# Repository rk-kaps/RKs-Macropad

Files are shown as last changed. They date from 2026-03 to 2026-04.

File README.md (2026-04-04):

<h1 align="center">RKs Macropad</h1>

<p align="center">
  Welcome to RKs Macropad, my custom 3D printed Macropad that runs KMK firmware.
</p>

<p align="center">
  Main
</p>

<p align="center">
  Exploded
</p>

<hr>
<h2>PCB & Schematic</h2>
<p align="center">
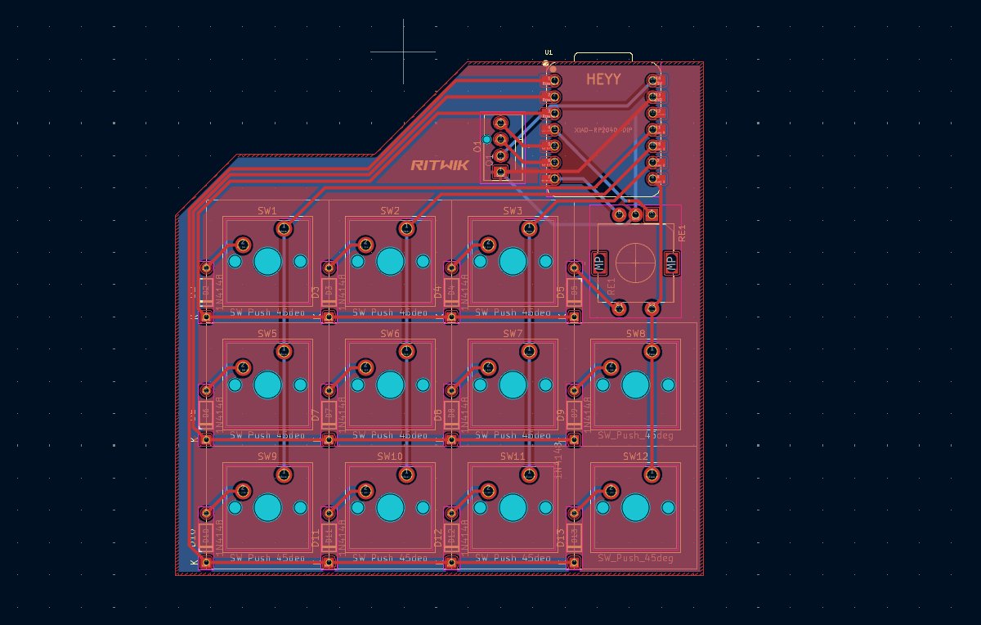
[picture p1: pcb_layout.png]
PCB Layout
  
  <br><em>PCB Layout (KiCad)</em>
</p>
<p align="center">
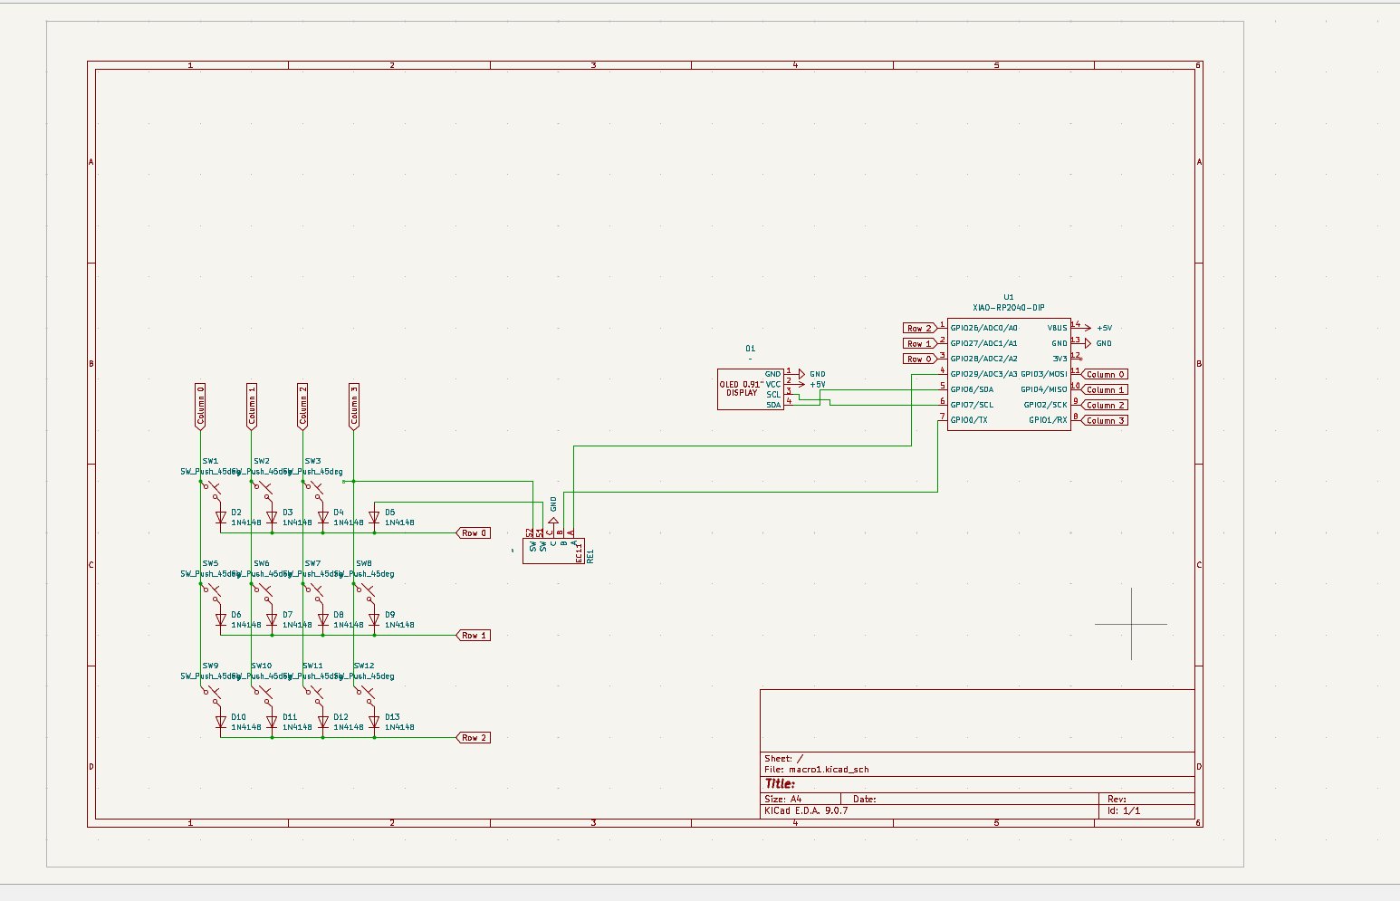
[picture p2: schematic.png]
Schematic
  
  <br><em>Schematic</em>
</p>
<p align="center">
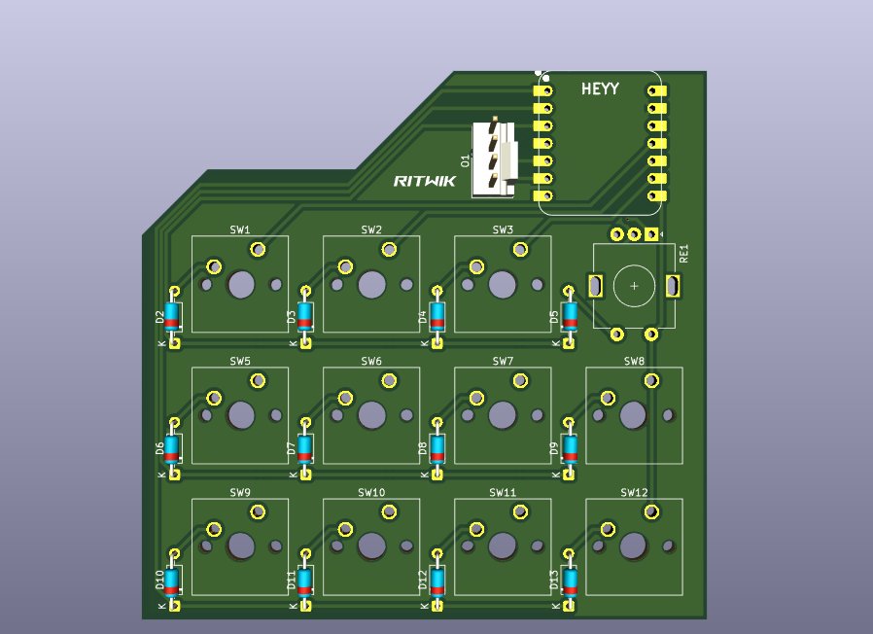
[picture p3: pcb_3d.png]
PCB 3D View
  
  <br><em>PCB 3D Render</em>
</p>

<h2>Motivation</h2>
<ul>>
MacroPad began as a simple rotary encoder-based volume controller. It evolved into a fully-featured macropad focused on:

Speeding up workflows
Reducing repetitive actions
Providing intuitive visual feedback
Maximizing functionality within hardware constraints
</ul>
</h2>
<h2> Project Highlights  </h2>
<ul>
- Efficient use of limited GPIO resources  
- Custom analog decoding for rotary encoder  
- Integration of hardware + firmware + UI design  
- Fully functional productivity tool
</ul>
<hr>

<h2>Bill of Materials:</h2>

<ul>
  <li>1x Rks Macropad PCB</li>
  <li>1x XIAO-PR2040-DIP</li>
  <li>1x EC11 rotary encoder</li>
  <li>11x Cherry MX (or equivalent) keyswitches</li>
  <li>11x Keycaps</li>
  <li>12x 1N4148 Throughhole diodes</li>
  <li>1x 0.91 inch OLED display (SSD1306 I2C 0.91 128x32)</li>
  <li>4x Cap head M3x16 machine screws</li>
  <li>1x 3D printed shell top half</li>
  <li>1x 3D printed shell bottom half</li>
</ul>

<p>
  small amount of spare wire apprx. 50mm worth.
</p>
<hr>
<h2>Instructions for Assembly</h2>
<ol>
  <li>Solder RP2040 directly onto the PCB without a header.</li>
  <li>Solder on diodes aligning with the silkscreen.</li>
  <li>Solder Cherry MX switches to board.</li>
  <li>
    Solder breakout cables to the spare 4 pins near the RP2040 — these will be used to wire to the OLED display.
    Make these breakout cables ~2" to allow for easier soldering.
  </li>
  <li>
    Clamshell the base around the PCB, passing the breakout cables through the small hole in the gap for the display
    in the top half of the case, then use the M3x16 machine screws to clamp the assembly together.
  </li>
  <li>Solder display to the breakout cables.</li>
  <li>Use double-sided tape or a light adhesive to hold the OLED into its holder.</li>
</ol>
<hr>
<h2>Acknowledgements</h2>
<ul>
- KMK Firmware Community  
- Good people of Hack Club
</ul>
<hr>

<h2>Instructions for Assembly:</h2>

<ol>
  <li>Solder RP2040 directly onto the pcb without a header.</li>
  <li>Solder on Diodes aligning with the slikscreen.</li>
  <li>Solder CherryMX switches to board.</li>
  <li>
    Solder breakout cables to the spare 4 pins near the RP2040, these will be used to wire to the OLED display.
    Make these breakout cables ~2" to allow for easier soledering.
  </li>
  <li>
    Clamshell the base around the PCB, passing the breakout cables through the small hole in the gap for the display
    in the top half of the case, then use the M3x16 machine screws to clamp the assembly together.
  </li>

  <li>Solder display to the breakout cables</li>
  <li>Use double-sided tape or a light adhesive to hold the OLED into its holder,.</li>

<h2> Acknowledgements  </h2>
<ul>
- KMK Firmware Community  
- Good people of Hack Club</ul>

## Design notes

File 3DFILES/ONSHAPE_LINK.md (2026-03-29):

# Rks Macropad — Onshape CAD Document

 [Open in Onshape]https://cad.onshape.com/documents/129b0d111c52e735cc28273f

## Exported Files

The full assembly is also available as a STEP file for use in any CAD software

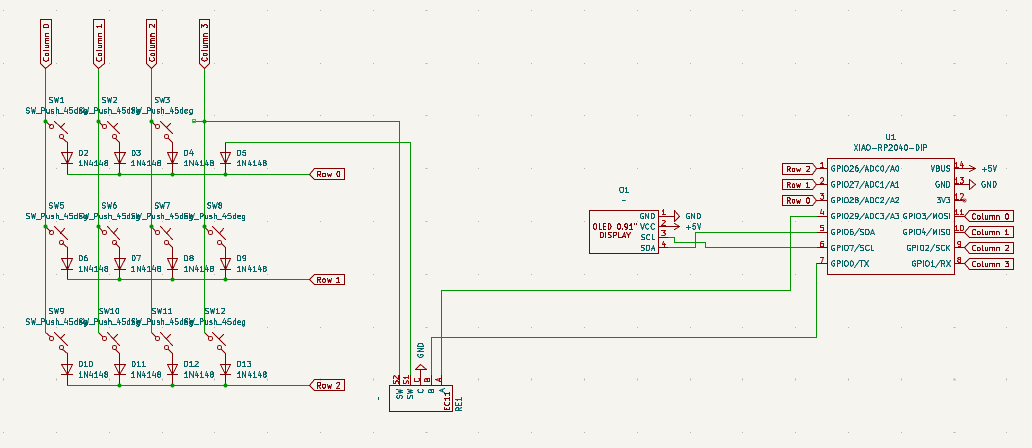
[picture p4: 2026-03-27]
README/Schematic.png

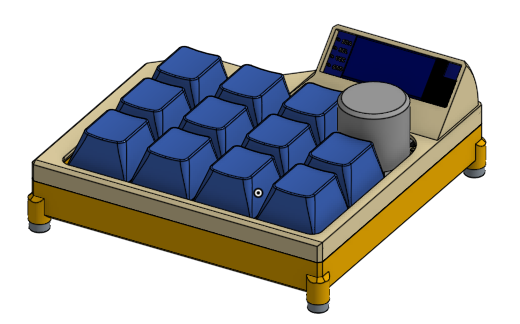
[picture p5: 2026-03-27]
README/Main.png

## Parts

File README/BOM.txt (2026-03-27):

Bill of Materials:
1x CyberDock PCB
1x XIAO-PR2040-DIP
1x EC11 rotary encoder
11x Cherry MX (or equivalent) keyswitches
11x Keycaps
12x 1N4148 Throughhole diodes
1x 0.91 inch OLED display (SSD1306 I2C 0.91 128x32)
4x Cap head M3x16 machine screws
1x 3D printed shell top half
1x 3D printed shell bottom half

small amount of spare wire apprx. 50mm worth.

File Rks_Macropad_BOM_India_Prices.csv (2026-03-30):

Ref | Component | Manufacturer | Qty | Unit Price (₹) | Total (₹) | Store | Link
PCB | Rks Macropad PCB | Custom | 1 | 250 | 250 | JLCPCB | https://jlcpcb.com
MCU | XIAO-RP2040-DIP | Seeed Studio | 1 | 914 | 914 | Robocraze | https://robocraze.com/products/seeed-studio-xiao-rp2040-development-board
ENC | EC11 Rotary Encoder w/ Push Button | Hongyan | 1 | 52 | 52 | Robu.in | https://robu.in/product/hongyan-ec11h-7ce15p1zy15f7-rotary-encoder-with-push-button-switch-vertical-plug-in/
SW | Cherry MX RGB Switch (pack of 10) | Cherry | 2 | 350 | 700 | Meckeys | https://meckeys.com/shop/accessories/keyboard-accessories/key-switches/cherry-mx-rgb-switch/
KP | Keycaps MX compatible (set) | Generic | 1 | 499 | 499 | Meckeys | https://meckeys.com/category/accessories/keyboard-accessories/keycaps/
D | 1N4148 Through-hole Diode | OnSemi | 12 | 1 | 12 | Robu.in | https://robu.in/product/diode-1n4148/
OLED | 0.91" OLED SSD1306 I2C 128x32 | Generic | 1 | 149 | 149 | Robu.in | https://robu.in/product/0-91-inch-128x32-i2c-iic-serial-blue-oled-lcd-display-module/
SCR | Cap Head M3x16 Allen Bolt (12 pcs) | EasyMech | 1 | 89 | 89 | Robu.in | https://robu.in/product/easymech-set-m3-x-16mm-socket-head-cap-allen-bolt-nut-12-pcs/
SHL-T | 3D Printed Shell - Top Half | will get it -printed | 1 | 150 | 150 | 3Ding.in | https://www.3ding.in
SHL-B | 3D Printed Shell - Bottom Half | will get it -printed | 1 | 150 | 150 | 3Ding.in | https://www.3ding.in
 |  |  |  | TOTAL | 2965

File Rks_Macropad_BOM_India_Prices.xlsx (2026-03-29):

Rks Macropad — Bill of Materials (India Prices, Mar 2026)
Ref | Component | Manufacturer | Qty | Unit Price (₹) | Total (₹) | Store | Link
PCB | Rks Macropad PCB | Custom | 1 | 250 |  | JLCPCB | Link (https://jlcpcb.com)
MCU | XIAO-RP2040-DIP | Seeed Studio | 1 | 914 |  | Robocraze | Link (https://robocraze.com/products/seeed-studio-xiao-rp2040-development-board)
ENC | EC11 Rotary Encoder w/ Push Button | Hongyan | 1 | 52 |  | Robu.in | Link (https://robu.in/product/hongyan-ec11h-7ce15p1zy15f7-rotary-encoder-with-push-button-switch-vertical-plug-in/)
SW | Cherry MX RGB Switch (pack of 10) | Cherry | 2 | 350 |  | Meckeys | Link (https://meckeys.com/shop/accessories/keyboard-accessories/key-switches/cherry-mx-rgb-switch/)
KP | Keycaps MX compatible (set) | Generic | 1 | 499 |  | Meckeys | Link (https://meckeys.com/category/accessories/keyboard-accessories/keycaps/)
D | 1N4148 Through-hole Diode | OnSemi | 12 | 1 |  | Robu.in | Link (https://robu.in/product/diode-1n4148/)
OLED | 0.91" OLED SSD1306 I2C 128x32 | Generic | 1 | 149 |  | Robu.in | Link (https://robu.in/product/0-91-inch-128x32-i2c-iic-serial-blue-oled-lcd-display-module/)
SCR | Cap Head M3x16 Allen Bolt (12 pcs) | EasyMech | 1 | 89 |  | Robu.in | Link (https://robu.in/product/easymech-set-m3-x-16mm-socket-head-cap-allen-bolt-nut-12-pcs/)
SHL-T | 3D Printed Shell - Top Half | Self-printed | 1 | 150 |  | 3Ding.in | Link (https://www.3ding.in)
SHL-B | 3D Printed Shell - Bottom Half | Self-printed | 1 | 150 |  | 3Ding.in | Link (https://www.3ding.in)
 |  |  |  | TOTAL:
* Prices are approximate as of March 2026. PCB & 3D print costs are estimates. Cherry MX pack of 10 ordered x2 for 11 switches needed.

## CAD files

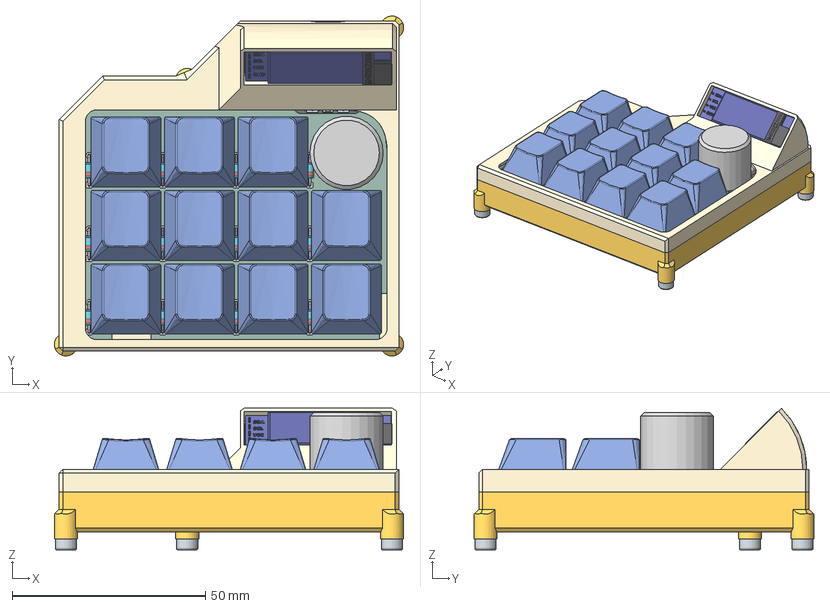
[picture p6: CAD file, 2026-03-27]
3DFILES/macro.step
90.5 x 88.1 x 36.7 mm
Hex socket head cap screw M3x0.50 x 16 x 4
r1_100 x 11
Case Bottom
Case Top
MX? ??LEDLEDLED x 55
MX ? ??��_�?�__ x 11
??___??__�_ x 22
MX ? ???_�___�1 x 11
MX? ?? ?? ?�2__??_�2____�_ x 11
Knob
��ת������ x 6
type-c v2 x 24
main x 16
smd_button v3
smd_button v3(Mirror)
VSS
VDD
DIN
DOUT
D_DO-35_SOD27_P7.62mm_Horizontal x 24

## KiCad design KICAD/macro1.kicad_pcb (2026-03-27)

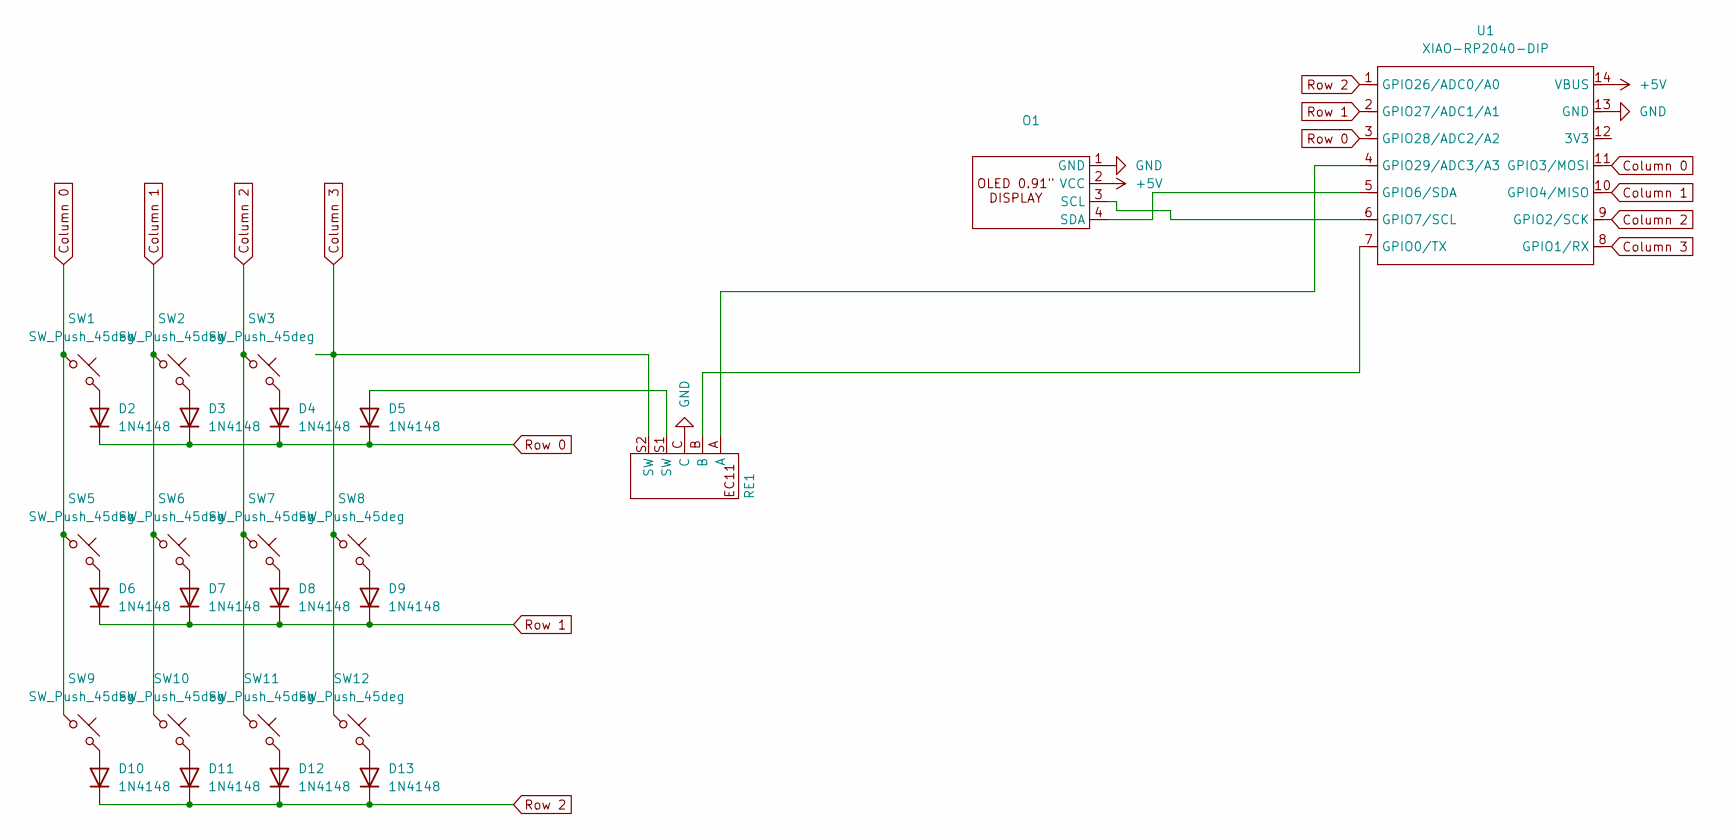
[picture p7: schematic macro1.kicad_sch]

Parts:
D2, D3, D4, D5, D6, D7, D8, D9, D10, D11, D12, D13: 1N4148; D_DO-35_SOD27_P7.62mm_Horizontal
O1: FanPinHeader_1x04_P2.54mm_Vertical
RE1: RotaryEncoder_Alps_EC11E-Switch_Vertical_H20mm
SW1, SW2, SW3, SW5, SW6, SW7, SW8, SW9, SW10, SW11, SW12: SW_Push_45deg; SW_Cherry_MX_1.00u_PCB
U1: XIAO-RP2040-DIP

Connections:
+5V: O1.2 (VCC), U1.14 (VBUS)
Column 0: SW1.1, SW5.1, SW9.1, U1.11 (GPIO3/MOSI)
Column 1: SW2.1, SW6.1, SW10.1, U1.10 (GPIO4/MISO)
Column 2: SW3.1, SW7.1, SW11.1, U1.9 (GPIO2/SCK)
Column 3: RE1.S2 (SW), SW8.1, SW12.1, U1.8 (GPIO1/RX)
GND: O1.1 (GND), RE1.C, U1.13 (GND)
unnamed: D2.2 (A), SW1.2
unnamed: D3.2 (A), SW2.2
unnamed: D4.2 (A), SW3.2
unnamed: D5.2 (A), RE1.S1 (SW)
unnamed: D6.2 (A), SW5.2
unnamed: D7.2 (A), SW6.2
unnamed: D8.2 (A), SW7.2
unnamed: D9.2 (A), SW8.2
unnamed: D10.2 (A), SW9.2
unnamed: D11.2 (A), SW10.2
unnamed: D12.2 (A), SW11.2
unnamed: D13.2 (A), SW12.2
unnamed: O1.3 (SCL), U1.6 (GPIO7/SCL)
unnamed: O1.4 (SDA), U1.5 (GPIO6/SDA)
unnamed: RE1.B, U1.7 (GPIO0/TX)
unnamed: RE1.A, U1.4 (GPIO29/ADC3/A3)
Row 0: D2.1 (K), D3.1 (K), D4.1 (K), D5.1 (K), U1.3 (GPIO28/ADC2/A2)
Row 1: D6.1 (K), D7.1 (K), D8.1 (K), D9.1 (K), U1.2 (GPIO27/ADC1/A1)
Row 2: D10.1 (K), D11.1 (K), D12.1 (K), D13.1 (K), U1.1 (GPIO26/ADC0/A0)

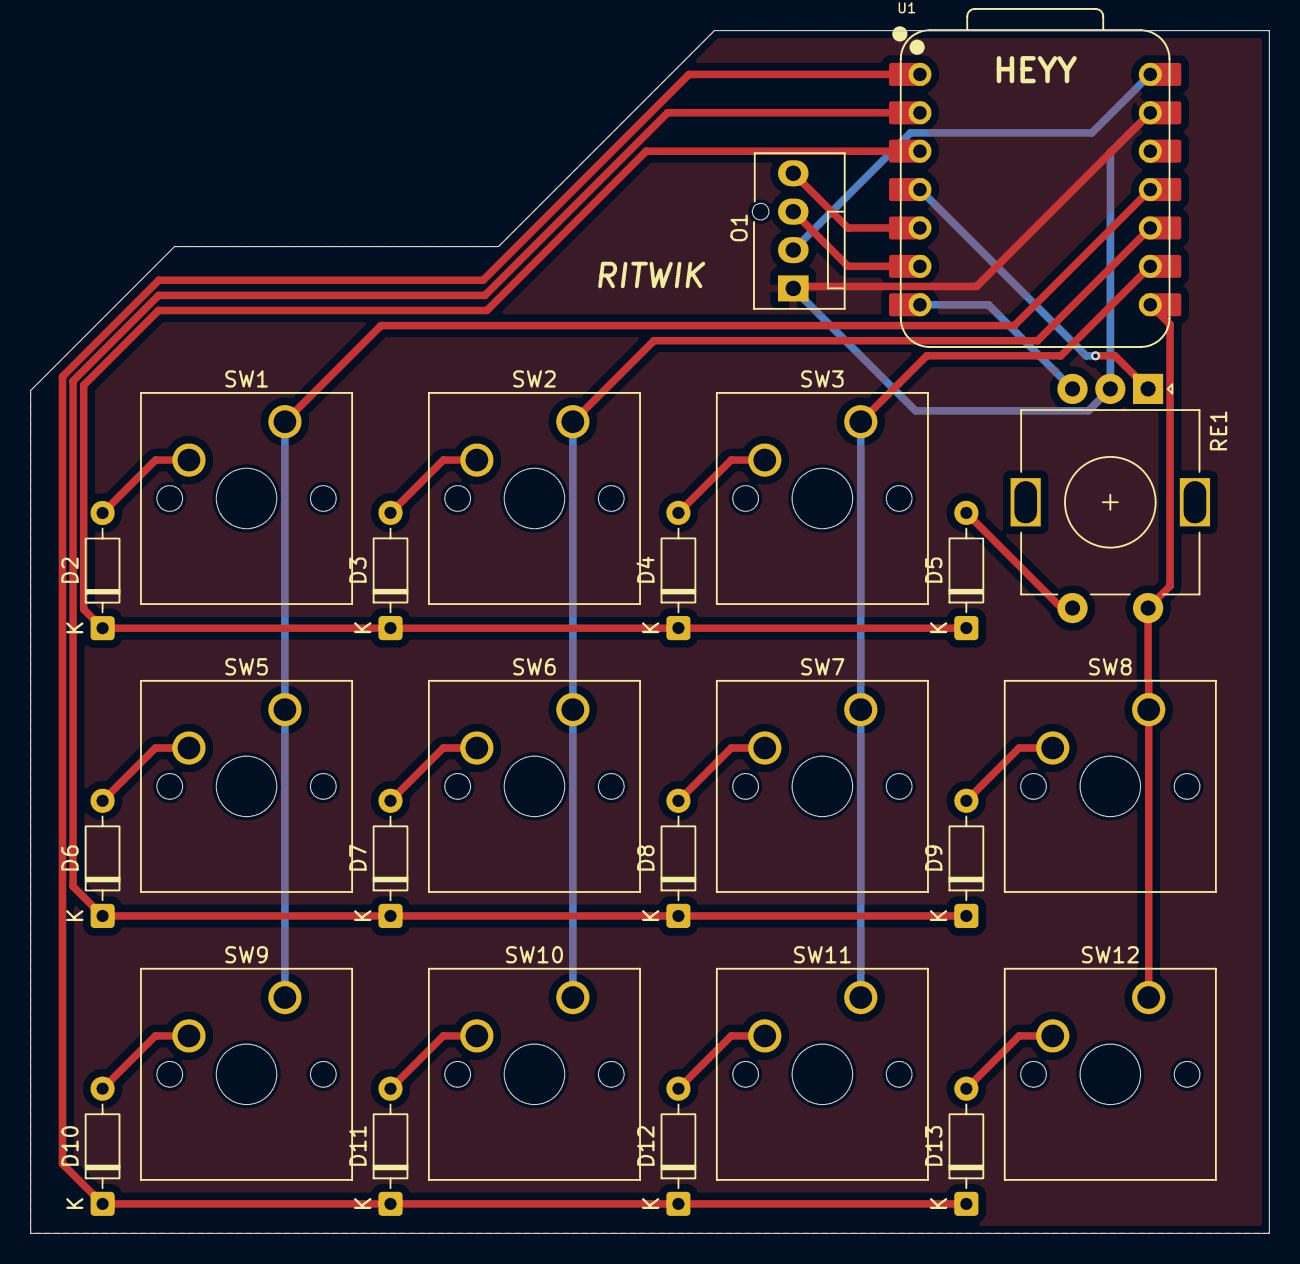
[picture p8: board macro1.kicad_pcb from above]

Board: 2 copper layers, 82.0 x 79.6 mm, 26 parts (0 on the bottom side), 25 nets.

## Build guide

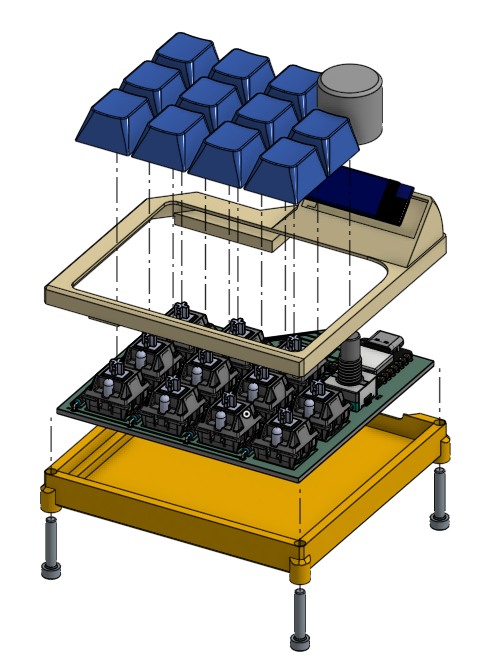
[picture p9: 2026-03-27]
README/deconstructed_view.png

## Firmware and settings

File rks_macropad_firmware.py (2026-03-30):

print("Starting Rks Macropad")
import board
import busio
import digitalio
import time
from kmk.kmk_keyboard import KMKKeyboard
from kmk.keys import KC
from kmk.scanners import DiodeOrientation
from kmk.extensions.media_keys import MediaKeys
from kmk.modules.layers import Layers
import adafruit_ssd1306

# --- OLED Setup ---
# IMPORTANT: Due to the display orientation in this build, the OLED is connected
# via breakout wires (not directly plugged into the PCB).
# Wire connections from Waveshare RP2040-Zero to SSD1306 OLED:
#   VCC  -> 3.3V pin on RP2040-Zero  ⚠️ DO NOT use 5V/VBUS — will damage the display
#   GND  -> GND
#   SDA  -> GP6
#   SCL  -> GP7
i2c = busio.I2C(board.GP7, board.GP6)  # SCL=GP7, SDA=GP6
oled = adafruit_ssd1306.SSD1306_I2C(128, 32, i2c)

# --- Layer Names ---
LAYER_NAMES = ["Main", "Onshape", "Reaper"]
current_layer = 0

# --- Key Labels per layer ---
LAYER_LABELS = [
    [
        ["PREV", "NEXT", "PLAY", "LYR"],
        ["SNIP", "SHOW", "LOCK", "EMOJI"],
        ["RUN",  "TABS", "MUTE", "DESK"],
    ],
    [
        ["SKTCH", "EXVW", "FIT",  "LYR"],
        ["FRONT", "RGHT", "TOP",  "MATE"],
        ["ZOOM+", "ZOOM-","ROT",  "LYR"],
    ],
    [
        ["PLAY", "STOP", "REC",  "LYR"],
        ["MUTE", "SOLO", "LOOP", "QTSE"],
        ["ZM+",  "ZM-",  "TAP",  "LYR"],
    ],
]

# --- Key Actions per layer ---
LAYER_ACTIONS = [
    [
        "Prev Track", "Next Track", "Play/Pause", "Next Layer",
        "Snip", "Show Desktop", "Lock", "Emoji",
        "Run", "Task View", "Mute", "New Desktop",
    ],
    [
        "Sketch", "Exit View", "Fit All", "Next Layer",
        "Front View", "Right View", "Top View", "Mate",
        "Zoom In", "Zoom Out", "Rotate", "Next Layer",
    ],
    [
        "Play", "Stop", "Record", "Next Layer",
        "Mute Track", "Solo Track", "Toggle Loop", "Quantise",
        "Zoom In", "Zoom Out", "Tap Tempo", "Next Layer",
    ],
]

TIMEOUT = 1
DISPLAY_INTERVAL = 0.5

last_action_time = None
last_display_update = 0
pending_action = None
pending_is_volume = False
volume_direction = None

def draw_static():
    oled.fill(0)
    layer_label = LAYER_NAMES[current_layer]
    oled.text(layer_label, 0, 0, 1)
    oled.fill_rect(0, 9, 128, 1, 1)
    labels = LAYER_LABELS[current_layer]
    for row in range(3):
        for col in range(4):
            x = col * 32
            y = 11 + row * 7
            oled.text(labels[row][col], x, y, 1)
    oled.show()

def show_action(label):
    global last_action_time
    oled.fill(0)
    char_width = 12
    text_width = len(label) * char_width
    x = max(0, (128 - text_width) // 2)
    y = 8
    oled.text(label, x, y, 1, size=2)
    oled.show()
    last_action_time = time.monotonic()

def show_volume(direction):
    oled.fill(0)
    label = "Vol Up" if direction == "up" else "Vol Down"
    char_width = 12
    text_width = len(label) * char_width
    x = max(0, (128 - text_width) // 2)
    y = 8
    oled.text(label, x, y, 1, size=2)
    oled.show()

def show_layer_name(name):
    oled.fill(0)
    char_w = 12
    text_w = len(name) * char_w
    x = max(0, (128 - text_w) // 2)
    oled.text(name, x, 8, 1, size=2)
    oled.show()

draw_static()

# --- Keyboard Setup ---
# Pin mapping verified from macro1.kicad_pcb / macro1.kicad_sch:
#   Col 0 -> GPIO4  (GP4)
#   Col 1 -> GPIO3  (GP3)
#   Col 2 -> GPIO2  (GP2)
#   Col 3 -> GPIO1  (GP1)
#   Row 0 -> GPIO28 (GP28)
#   Row 1 -> GPIO27 (GP27)
#   Row 2 -> GPIO26 (GP26)
# Matrix: 3 rows x 4 cols = 12 keys
keyboard = KMKKeyboard()
keyboard.col_pins = (board.GP4, board.GP3, board.GP2, board.GP1)
keyboard.row_pins = (board.GP28, board.GP27, board.GP26)
keyboard.diode_orientation = DiodeOrientation.COL2ROW
keyboard.extensions.append(MediaKeys())

layers_mod = Layers()
keyboard.modules.append(layers_mod)

LYR_MAIN    = KC.TO(0)
LYR_ONSHAPE = KC.TO(1)
LYR_REAPER  = KC.TO(2)

keyboard.keymap = [
    # Layer 0 - Main
    [
        KC.MPRV,                    KC.MNXT,           KC.MPLY,                 LYR_ONSHAPE,
        KC.LGUI(KC.LSFT(KC.S)),     KC.LGUI(KC.D),     KC.LGUI(KC.L),           KC.LGUI(KC.DOT),
        KC.LGUI(KC.R),              KC.LGUI(KC.TAB),   KC.MUTE,                 KC.LCTL(KC.LGUI(KC.D)),
    ],
    # Layer 1 - Onshape
    [
        KC.S,                       KC.E,              KC.F,                    LYR_REAPER,
        KC.LCTL(KC.NUM_1),          KC.LCTL(KC.NUM_2), KC.LCTL(KC.NUM_3),       KC.M,
        KC.LCTL(KC.EQUAL),          KC.LCTL(KC.MINUS), KC.LCTL(KC.R),           LYR_REAPER,
    ],
    # Layer 2 - Reaper
    [
        KC.SPACE,                   KC.LCTL(KC.SPACE), KC.LCTL(KC.LSFT(KC.R)), LYR_MAIN,
        KC.F6,                      KC.F8,             KC.LCTL(KC.L),           KC.LCTL(KC.LSFT(KC.Q)),
        KC.LCTL(KC.EQUAL),          KC.LCTL(KC.MINUS), KC.LALT(KC.LSFT(KC.T)), LYR_MAIN,
    ],
]

# --- Encoder Setup ---
# Pin mapping verified from macro1.kicad_pcb:
#   Pad A (CLK) -> GPIO29 -> GP29
#   Pad B (DT)  -> GPIO0  -> GP0
#   Pad C       -> GND (common ground)
#   Pad S2      -> Column 3 (encoder push handled as a matrix key)
clk = digitalio.DigitalInOut(board.GP29)
clk.direction = digitalio.Direction.INPUT
clk.pull = digitalio.Pull.UP

dt = digitalio.DigitalInOut(board.GP0)
dt.direction = digitalio.Direction.INPUT
dt.pull = digitalio.Pull.UP

ENCODER_TABLE = {
    (1, 1, 0, 1): -1,
    (0, 1, 0, 0): -1,
    (0, 0, 1, 0): -1,
    (1, 0, 1, 1): -1,
    (1, 1, 1, 0): +1,
    (1, 0, 0, 0): +1,
    (0, 0, 0, 1): +1,
    (0, 1, 1, 1): +1,
}

last_clk = int(clk.value)
last_dt = int(dt.value)
accumulated = 0

_original_main_loop = keyboard._main_loop
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
